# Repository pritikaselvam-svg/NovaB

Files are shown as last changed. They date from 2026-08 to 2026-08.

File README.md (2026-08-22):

# 🎧 NovaBuds

### An end-to-end headphone concept combining industrial design, ergonomics, embedded electronics and custom PCB development.

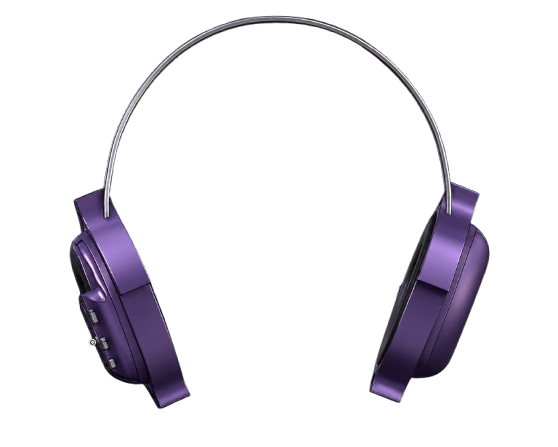
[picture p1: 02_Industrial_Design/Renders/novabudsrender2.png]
NovaB Hero


---

## What if I could take a pair of headphones from a concept sketch all the way to the electronics?

NovaBuds started with that question.

What began as a headphone design exercise turned into an exploration of what happens when **industrial design and electrical engineering are developed together**.

I designed the headphone form and ergonomics, developed the earcup and headband in CAD, designed the electronics architecture, built the schematic in KiCad, created a custom-shaped PCB around the product geometry, planned the embedded system and designed the ambient display interface.

The goal was not just to make a headphone that looked interesting.

It was to understand what it takes to make the **product, electronics and interaction work as one system.**

---

# ✦ Project Snapshot

| | |
|---|---|
| **Project** | NovaBuds |
| **Type** | Headphone / Wearable Electronics |
| **Focus** | Industrial Design × Embedded Systems |
| **CAD** | Onshape |
| **PCB Design** | KiCad |
| **MCU** | ESP32-S3-WROOM |
| **Charging** | BQ24074 |
| **Regulation** | AP2112K 3.3 V |
| **Audio** | I²S + MAX98357A |
| **Sensing** | Hall-effect sensor |
| **Interface** | TFT ambient display + physical buttons |
| **PCB** | Custom-shaped |
| **Status** | Engineering prototype in development |

---

# 01 — The Idea

Most headphone projects begin with either the industrial design or the electronics.

I wanted to explore both at the same time.

The starting point was a wearable form that could accommodate:

- a custom earcup geometry
- a headband structure
- a local display
- physical controls
- a battery
- audio electronics
- a wireless MCU
- a custom PCB

That immediately created an interesting constraint:

> **The electronics couldn't simply be designed first and placed inside a box afterwards.**

The product geometry had to influence the electronics.

And the electronics had to influence the product geometry.

---

# 02 — Product Direction

NovaBuds is designed around three ideas:

### 01. Product form

A distinctive earcup geometry developed around the human-facing side of the product rather than around a conventional rectangular electronics package.

### 02. Ambient interaction

A small display provides glanceable information such as playback state, battery and connectivity without requiring the user to constantly reach for a phone.

### 03. Integrated engineering

The mechanical enclosure, PCB and interaction system are treated as parts of the same product rather than independent projects.

---

# 03 — From Sketch to CAD

The first iterations were developed through physical sketches and form exploration.

The form was then developed in Onshape into the final earcup and headband geometry.

### CAD development

The CAD work focused on:

- earcup geometry
- headband structure
- component packaging
- display placement
- button placement
- internal volume
- PCB integration
- enclosure transitions

The final assembly was developed as a complete headphone rather than as isolated parts.

---

# 04 — Ergonomics

Because the product is worn directly on the head, the geometry had to be considered from the user's perspective.

The main ergonomic considerations were:

- ear clearance
- contact surfaces
- enclosure thickness
- edge transitions
- button reach
- display visibility
- headband geometry
- internal component clearance

The controls were positioned on the earcup so that common interactions could be performed without relying entirely on a phone.

The display was treated as an **ambient information surface** rather than a miniature smartphone screen.

> The current geometry is a design exploration. Formal anthropometric studies and physical user testing are planned for future iterations.

---

# 05 — Electronics Architecture

The electronics were designed around an ESP32-S3 as the central controller.

```text
                         ┌────────────────────┐
                         │      ESP32-S3      │
                         │   MCU + Wireless   │
                         └─────────┬──────────┘
                                   │
              ┌────────────────────┼────────────────────┐
              │                    │                    │
              ▼                    ▼                    ▼
         TFT Display           Buttons             Hall Sensor
              │
              │
              └─────────────────────┐
                                    │
                                    ▼
ESP32-S3 ─────── I²S ───────► MAX98357A ───────► Speaker

USB-C ───────► BQ24074 ───────► Li-ion Battery
                    │
                    ▼
                 AP2112K
                    │
                   3V3
                    │
                    └──────► Digital Electronics

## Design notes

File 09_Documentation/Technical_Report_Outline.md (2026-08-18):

# NovaBuds Technical Report

## 1. Introduction

Motivation for taking a headphone from concept to engineering
implementation.

## 2. Design Objectives

Ergonomics, product identity, embedded interaction, custom electronics
and compact packaging.

## 3. Industrial Design

Sketches, CAD evolution, enclosure geometry, headband, controls and
display.

## 4. Electronics

ESP32-S3, charging, regulation, audio, display, Hall sensing and
buttons.

## 5. PCB

Schematic, component selection, footprints, placement, custom outline,
routing, copper and DRC.

## 6. Firmware

Architecture and planned peripheral interfaces.

## 7. UI/UX

Ambient display and physical control concept.

## 8. Manufacturing

PCB fabrication, enclosure manufacturing and assembly.

## 9. Validation

Separate design assumptions from measured results.

## 10. Limitations

State what has not been physically tested.

## 11. Future Work

Fabrication, bring-up, firmware, acoustic testing and ergonomic testing.

## 12. Conclusion

Position NovaBuds as an integrated product-development exercise.

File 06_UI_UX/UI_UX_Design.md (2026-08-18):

# UI / UX Design

## Concept

Use an ambient display to surface useful information without requiring a
phone for every interaction.

## Information hierarchy

### Home

Connection, battery, playback state.

### Now Playing

Artwork, title, artist, playback state.

### Controls

Previous, play/pause, next, volume.

### Settings

Bluetooth, display and audio.

## Physical controls

Three buttons provide direct interaction. Exact mapping should be
validated through user testing.

## Design principles

-   Glanceable
-   Minimal
-   Clear state changes
-   Low interaction cost
-   Consistent hierarchy

## Validation questions

-   Can the current state be understood in two seconds?
-   Can common controls be used without a phone?
-   Is the display readable while worn?
-   Are icons understandable?

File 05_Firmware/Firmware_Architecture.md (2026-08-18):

# Firmware Architecture

## Target

ESP32-S3

## Proposed structure

``` text
main
├── bluetooth
├── audio
├── display
├── buttons
├── hall_sensor
├── power
└── ui_state
```

## Responsibilities

**Bluetooth:** pairing, connection state, control events.

**Display:** initialization, rendering, status updates.

**Buttons:** GPIO reading, debounce, action mapping.

**Hall sensor:** state detection and transitions.

**Audio:** I²S configuration and audio path.

**UI state:** HOME, NOW_PLAYING, VOLUME, BATTERY, BLUETOOTH, SETTINGS.

## Status

Architecture planned. Do not claim firmware functionality until it is
implemented and tested on hardware.

## Bring-up milestones

1.  Boot/serial.
2.  GPIO.
3.  Display.
4.  Buttons.
5.  Hall sensor.
6.  I²S.
7.  Amplifier/audio.
8.  Bluetooth.
9.  UI state machine.
10. Integrated power states.

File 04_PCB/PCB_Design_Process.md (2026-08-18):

# PCB Design Process

## Workflow

Schematic → Annotate → Footprints → ERC → Update PCB → Board outline →
Placement → Routing → Copper pour → DRC → 3D inspection → Gerbers

## Placement priorities

1.  Mechanical interfaces.
2.  ESP32-S3 antenna keepout.
3.  Power subsystem grouping.
4.  Audio path.
5.  Low-speed control signals.

## Routing priorities

1.  Power.
2.  Ground/return paths.
3.  Clock/data interfaces.
4.  I²S.
5.  Low-speed GPIO.

## Custom board outline

The outer boundary belongs on **Edge.Cuts** and must be a single closed,
non-self-intersecting contour.

Reference geometry should be placed on a user drawing layer, not
Edge.Cuts.

## Copper

Use a ground copper pour where appropriate and refill after routing
changes.

## DRC

Run DRC after major routing, outline, footprint and copper changes. Save
a screenshot of the final result.

## Status

-   Schematic: designed
-   Footprints: assigned
-   Placement: iterated
-   Routing: iterated
-   Copper pour: completed
-   Custom outline: created
-   DRC: iterated
-   Fabrication: pending

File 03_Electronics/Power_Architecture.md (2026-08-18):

# Power Architecture

``` text
USB-C VBUS
     │
     ▼
BQ24074
     ├────────► Li-ion Battery
     │
     ▼
AP2112K
     │
     ▼
3V3
 ├── ESP32-S3
 ├── Hall sensor
 ├── Display logic if compatible
 └── Other digital peripherals
```

## BQ24074

Document and verify: - ISET - ILIM - TS - EN1 - EN2 - CE - BAT - OUT -
GND/VSS

Exact resistor values and control states must be checked against the
selected BQ24074 datasheet and intended battery.

## 3.3 V

AP2112K input/output capacitors must be placed according to the
datasheet and close to the regulator pins.

## USB-C

For a USB-C power-only sink architecture, CC pins require appropriate
pull-down resistors. Verify the exact connector footprint and
implementation.

## Validation

Measure USB VBUS, charger output, battery voltage, regulator
input/output, 3V3 ripple, charging current and regulator temperature.

Do not connect a battery to a newly fabricated board until the power
path has been inspected and checked.

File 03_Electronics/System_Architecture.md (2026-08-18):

# Electronics System Architecture

``` text
                         ┌────────────────────┐
                         │      ESP32-S3      │
                         │   Main Controller  │
                         └─────────┬──────────┘
                                   │
          ┌────────────────────────┼─────────────────────────┐
          │                        │                         │
          ▼                        ▼                         ▼
      TFT Display             Hall Sensor               Buttons
                                   │
                                   │
                                I/O
                                   │
ESP32-S3 ───── I²S ─────► MAX98357A ─────► Speaker

USB-C ─────► BQ24074 ─────► Battery
                  │
                  ▼
             AP2112K
                  │
                 3V3
                  │
          Digital electronics
```

## Power

USB-C provides external power. BQ24074 manages the rechargeable
battery/power path. AP2112K provides the regulated digital 3.3 V rail.

## Digital

ESP32-S3 is the central controller for wireless connectivity and
peripheral control.

## Audio

ESP32-S3 → I²S → MAX98357A → speaker.

## Display

The display is mechanically separated from the main PCB and connected
through a dedicated connector. The exact pinout must match the chosen
display module.

## Hall sensor

A Hall-effect sensor is connected to a GPIO and positioned relative to a
magnet/mechanical feature.

## Engineering note

Final pin assignments, current requirements, decoupling, charge settings
and display protocol must be verified against the exact component/module
datasheets before fabrication.

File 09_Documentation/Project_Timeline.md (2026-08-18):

# Project Timeline

| Phase | Dates | Output |
| --- | --- | --- |
| **Concept** | **May 06–09, 2026** | Product direction |
| **Sketching** | **May 10–16, 2026** | Initial form |
| **Ergonomics** | **May 17–23, 2026** | Earcup geometry + control placement |
| **CAD** | **May 24–Jun 07, 2026** | Full headphone assembly |
| **Electronics Architecture** | **Jun 08–12, 2026** | System block diagram |
| **Schematic** | **Jun 13–22, 2026** | KiCad schematic |
| **Footprints** | **Jun 23–26, 2026** | Component footprints assigned |
| **PCB Placement** | **Jun 27–Jul 03, 2026** | Custom-shaped component layout |
| **Routing** | **Jul 04–14, 2026** | Routed PCB |
| **DRC + PCB Refinement** | **Jul 15–19, 2026** | Cleaned PCB + copper pour |
| **UI / UX** | **Jul 20–26, 2026** | Display screens + interaction concept |
| **Firmware Architecture** | **Jul 27–31, 2026** | Embedded software structure |
| **Fabrication** | **Aug 01–08, 2026** | Physical PCB |
| **Hardware Bring-up** | **Aug 09–15, 2026** | Initial electronics testing |
| **Integration** | **Aug 16–23, 2026** | Complete prototype |
| **Validation** | **Aug 24–30, 2026** | Electrical, ergonomic + functional measurements |
| **Final Documentation** | **Aug 31–Sep 06, 2026** | Portfolio + technical documentation |

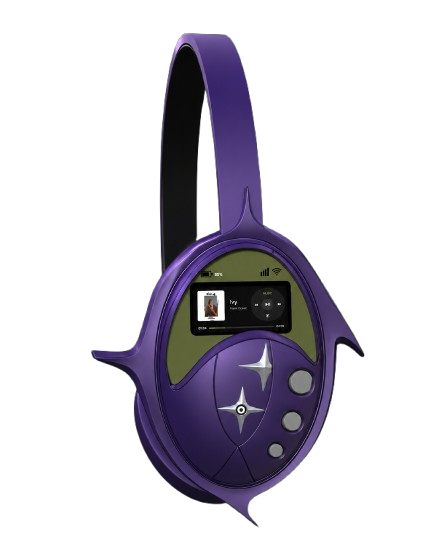
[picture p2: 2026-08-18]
10_Media/novabudsrender1.png

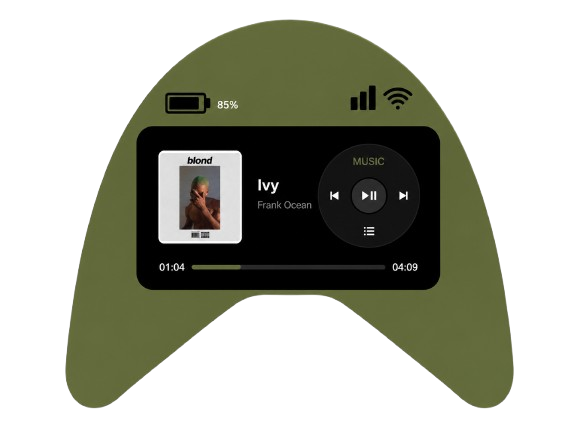
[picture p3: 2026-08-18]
06_UI_UX/NovaB UI.png

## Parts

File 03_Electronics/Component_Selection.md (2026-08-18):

# Component Selection

  Component        Function                     Why
  ---------------- ---------------------------- ---------------------------------
  ESP32-S3-WROOM   MCU/wireless                 Wireless + flexible peripherals
  BQ24074          Li-ion charging/power path   Dedicated battery management
  AP2112K          3.3 V LDO                    Compact digital regulation
  MAX98357A        I²S amplifier                Digital audio path
  A1104xLH         Hall sensor                  Solid-state magnetic sensing
  TFT display      Ambient interface            Local contextual information
  USB-C            Power input                  Common modern connector
  Li-ion battery   Energy storage               Rechargeable portable power
  Speaker          Audio output                 Acoustic transducer
  Push buttons     User input                   Tactile controls

## Verification before fabrication

-   [ ] Verify exact ESP32 module pinout.
-   [ ] Verify BQ24074 ISET/ILIM/TS/EN1/EN2/CE configuration.
-   [ ] Verify AP2112K exact output variant and capacitor requirements.
-   [ ] Verify MAX98357A package, supply and speaker requirements.
-   [ ] Verify exact display voltage, protocol and pinout.
-   [ ] Verify Hall sensor variant and output.
-   [ ] Verify USB-C footprint and CC resistor implementation.
-   [ ] Verify battery protection requirements.

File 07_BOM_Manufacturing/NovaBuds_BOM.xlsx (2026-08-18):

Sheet: BOM
Reference | Component | Function | Package / Footprint | Qty | Notes | Status
U1 | ESP32-S3-WROOM | MCU / wireless | RF module | 1 | Verify exact module pinout + antenna keepout | Designed
U2 | MAX98357A | I²S audio amplifier | Verify exact package | 1 | Verify supply and speaker requirements | Designed
U3 | A1104xLH | Hall sensor | SOT-23 | 1 | Verify exact variant | Designed
U4 | BQ24074 | Li-ion charger / power path | QFN | 1 | Verify ISET/ILIM/TS/EN1/EN2/CE | Designed
U6 | AP2112K-1.2 | 3.3 V LDO | SOT-23-5 | 1 | Verify exact ordering code | Designed
BT1 | 1-cell Li-ion battery | Energy storage | Battery connector/cell | 1 | Select protected cell/system | Concept
P1 | USB-C receptacle | Charging input | USB-C SMD | 1 | Verify exact footprint + CC network | Designed
LS1 | Speaker | Audio output | Mechanical part | 1 | Match amplifier requirements | Concept
J1 | 12-pin connector | Main interconnect | Verify selected footprint | 1 | Verify pinout | Designed
J2 | 12-pin connector | Interconnect | Verify selected footprint | 1 | Verify pinout | Designed
J3 | 8-pin connector | Display interface | 8-pin | 1 | Must match selected display | Designed
SW1 | Push button | User input | Verify selected footprint | 1 | GPIO | Designed
SW2 | Push button | User input | Verify selected footprint | 1 | GPIO | Designed
SW3 | Push button | User input | Verify selected footprint | 1 | GPIO | Designed

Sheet: Passives
Reference | Value | Function | Qty | Notes
R1 | 10k | ESP32 EN pull-up | 1 | Close to EN
R2 | 5.1k | USB-C CC pull-down | 1 | Verify CC implementation
R3 | 1.5k | BQ24074 configuration | 1 | Verify against datasheet
R4 | 2k | BQ24074 configuration | 1 | Verify against datasheet
R5 | 1.5k | BQ24074 configuration | 1 | Verify against datasheet
R6 | 1.5k | BQ24074 configuration | 1 | Verify against datasheet
R7 | 10k | GPIO pull-up where applicable | 1 | Verify firmware/hardware architecture
C1 | 10uF | Power decoupling | 1 | Near power IC
C2 | 10uF | Power decoupling | 1 | Near regulator
C3 | 10uF | Bulk decoupling | 1 | Near digital supply
C4 | 0.1uF | High-frequency decoupling | 1 | Near IC supply
C5 | 10uF | Bulk decoupling | 1 | Near digital supply

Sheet: PreFab_Checklist
Item | Check | Status
ESP32-S3 | Exact module/footprint verified | Pending
BQ24074 | Charge settings and control pins verified | Pending
AP2112K | Exact variant and capacitor requirements verified | Pending
MAX98357A | Exact package/speaker requirements verified | Pending
Display | Exact voltage/protocol/pinout verified | Pending
USB-C | Footprint and CC network verified | Pending
Battery | Protected cell/system selected | Pending
PCB | DRC clean | Pending
Edge.Cuts | Single closed outline | Pending
Connectors | Physical pin numbering verified | Pending

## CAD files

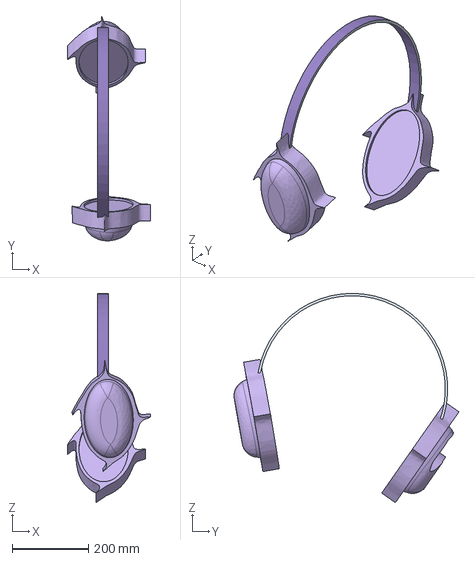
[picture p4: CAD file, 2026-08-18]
02_Industrial_Design/CAD/Assembly 1.step
217.7 x 588.7 x 547.5 mm

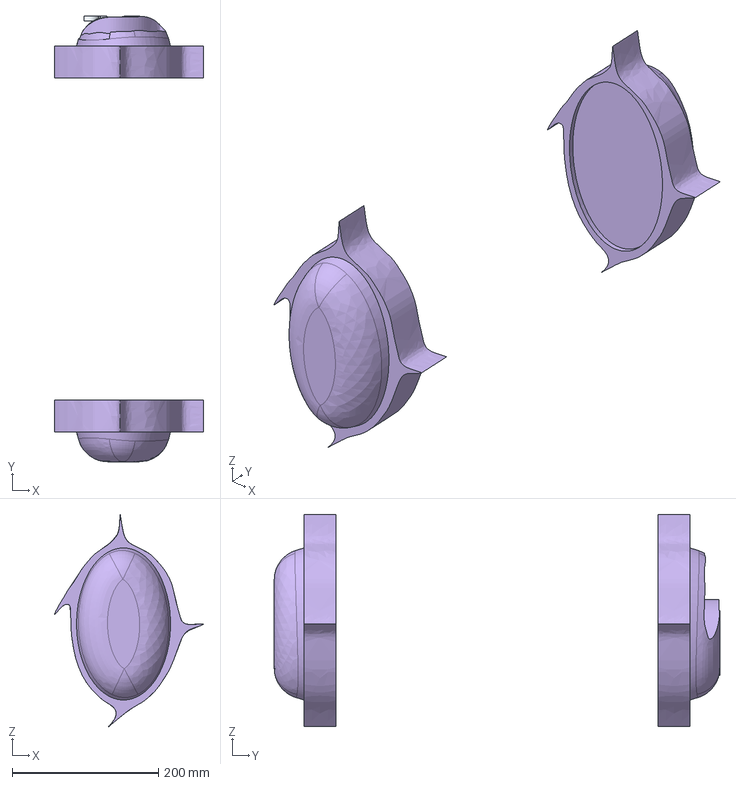
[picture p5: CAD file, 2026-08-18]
02_Industrial_Design/CAD/Part Studio 1.step
204.3 x 609.6 x 290.1 mm

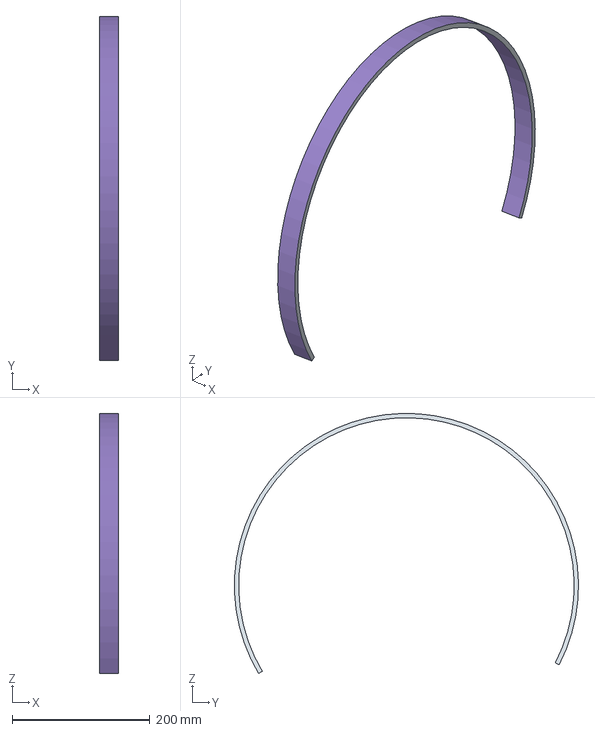
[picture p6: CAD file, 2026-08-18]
02_Industrial_Design/CAD/Part Studio 2.step
27.9 x 499.5 x 377.7 mm

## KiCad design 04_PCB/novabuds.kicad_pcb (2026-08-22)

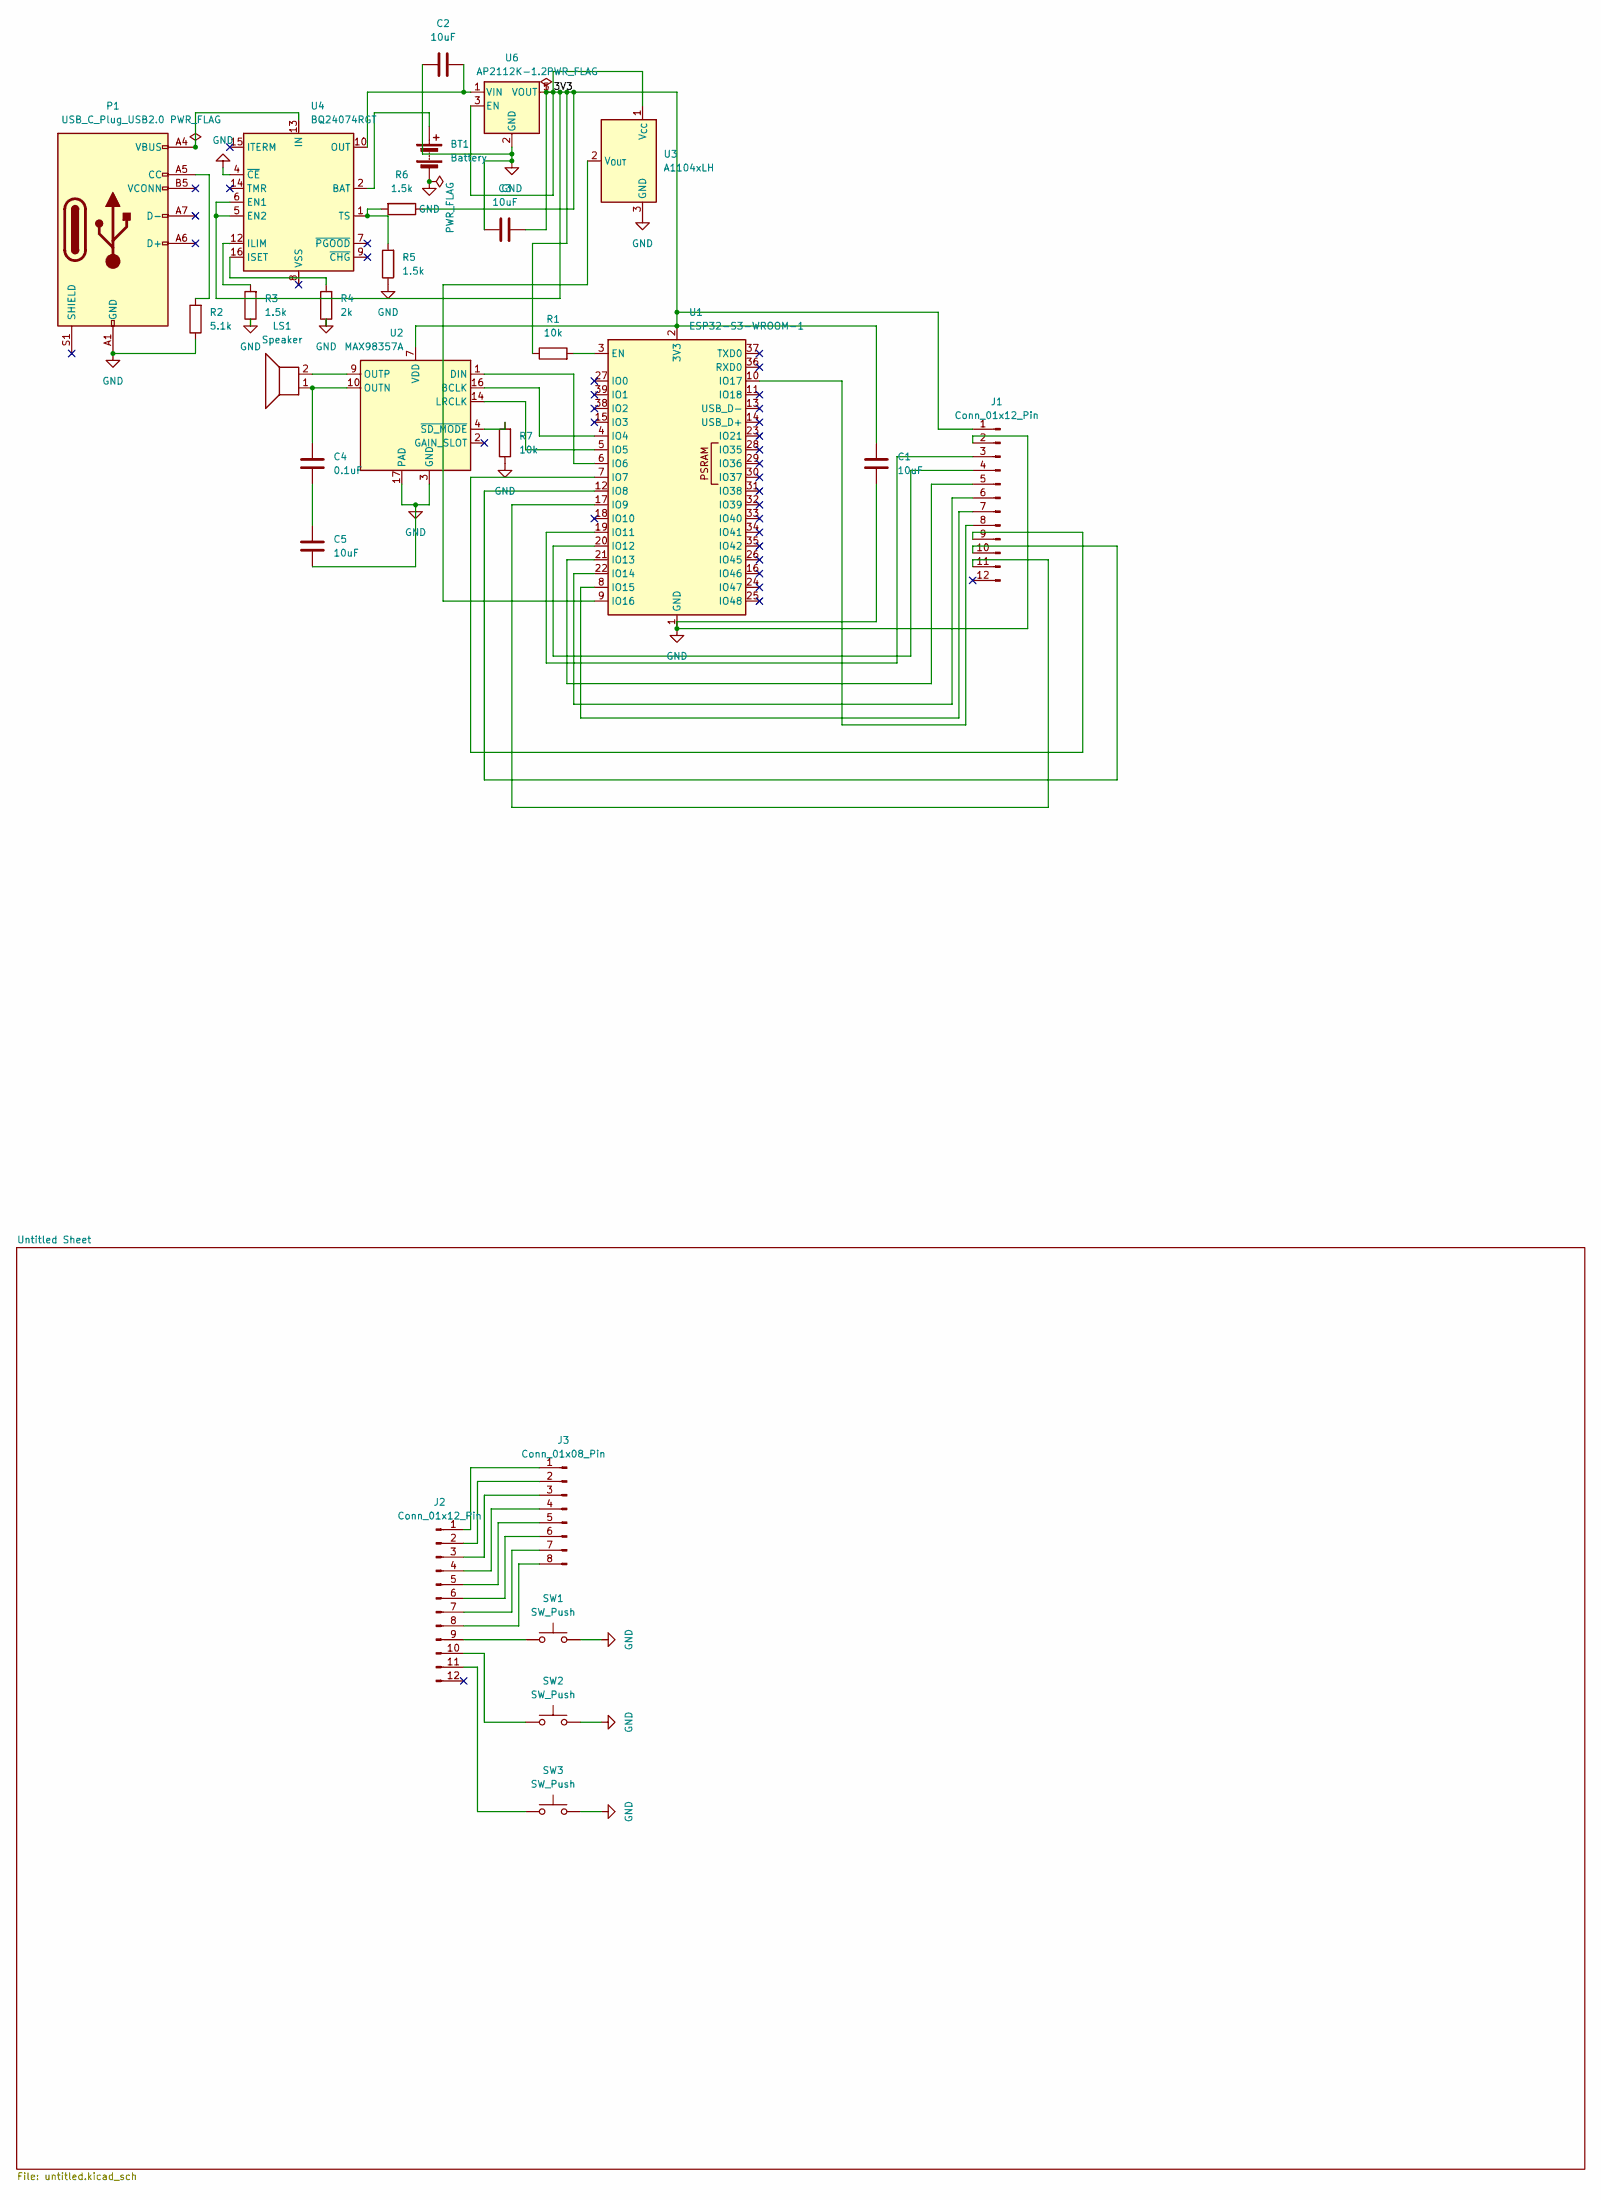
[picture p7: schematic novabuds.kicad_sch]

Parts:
BT1: Battery; JST_PH_B2B-PH-K_1x02_P2.00mm_Vertical
C1, C2, C3, C5: 10uF; C_0805_2012Metric
C4: 0.1uF; C_0805_2012Metric
J1, J2: Conn_01x12_Pin; PinHeader_1x12_P2.54mm_Vertical
J3: Conn_01x08_Pin; PinHeader_1x08_P2.54mm_Vertical
LS1: Speaker; PinHeader_1x02_P2.54mm_Vertical
P1: USB_C_Plug_USB2.0; USB_C_Receptacle_HRO_TYPE-C-31-M-12
R1, R7: 10k; R_0805_2012Metric
R2: 5.1k; R_0805_2012Metric
R3, R5, R6: 1.5k; R_0805_2012Metric
R4: 2k; R_0805_2012Metric
SW1, SW2, SW3: SW_Push; SW_PUSH_6mm
U1: ESP32-S3-WROOM-1
U2: MAX98357A; TQFN-16-1EP_3x3mm_P0.5mm_EP1.23x1.23mm
U3: A1104xLH; SOT-23W
U4: BQ24074RGT; VQFN-16-1EP_3x3mm_P0.5mm_EP1.6x1.6mm
U6: AP2112K-1.2; SOT-23-5

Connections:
/3V3: C1.1, C3.2, J1.1, R1.1, R6.1, U1.2 (3V3), U2.7 (VDD), U2.8 (VDD), U3.1 (V_{CC}), U4.5 (EN2), U4.6 (EN1), U6.3 (EN), U6.5 (VOUT)
GND: BT1.2 (-), C1.2, C2.1, C3.1, C5.2, J1.2, P1.A1 (GND), P1.A12 (GND), P1.B1 (GND), P1.B12 (GND), R2.1, R3.1, R4.1, R5.1, R7.1, SW1.2, SW2.2, SW3.2, U1.1 (GND), U1.40 (GND), U1.41 (GND), U2.3 (GND), U2.11 (GND), U2.15 (GND), U2.17 (PAD), U3.3 (GND), U4.4 (~CE), U6.2 (GND)
unnamed: BT1.1 (+), U4.2 (BAT), U4.3 (BAT)
unnamed: C4.2, C5.1
unnamed: J1.3, U1.19 (IO11)
unnamed: J1.4, U1.20 (IO12)
unnamed: J1.5, U1.21 (IO13)
unnamed: J1.6, U1.22 (IO14)
unnamed: J1.7, U1.8 (IO15)
unnamed: J1.8, U1.10 (IO17)
unnamed: J1.9, U1.7 (IO7)
unnamed: J1.10, U1.12 (IO8)
unnamed: J1.11, U1.17 (IO9)
unnamed: J2.1, J3.1
unnamed: J2.2, J3.2
unnamed: J2.3, J3.3
unnamed: J2.4, J3.4
unnamed: J2.5, J3.5
unnamed: J2.6, J3.6
unnamed: J2.7, J3.7
unnamed: J2.8, J3.8
unnamed: J2.9, SW1.1
unnamed: J2.10, SW2.1
unnamed: J2.11, SW3.1
unnamed: P1.A5 (CC), R2.2
unnamed: R1.2, U1.3 (EN)
unnamed: U1.4 (IO4), U2.16 (BCLK)
unnamed: U1.5 (IO5), U2.14 (LRCLK)
unnamed: U1.6 (IO6), U2.1 (DIN)
unnamed: U1.9 (IO16), U3.2 (V_{OUT})
unnamed: C4.1, LS1.1, U2.10 (OUTN)
unnamed: LS1.2, U2.9 (OUTP)
unnamed: R7.2, U2.4 (~SD_MODE)
unnamed: R3.2, U4.12 (ILIM)
unnamed: P1.A4 (VBUS), P1.A9 (VBUS), P1.B4 (VBUS), P1.B9 (VBUS), U4.13 (IN)
unnamed: R4.2, U4.16 (ISET)
unnamed: R5.2, R6.2, U4.1 (TS)
unnamed: C2.2, U4.10 (OUT), U4.11 (OUT), U6.1 (VIN)

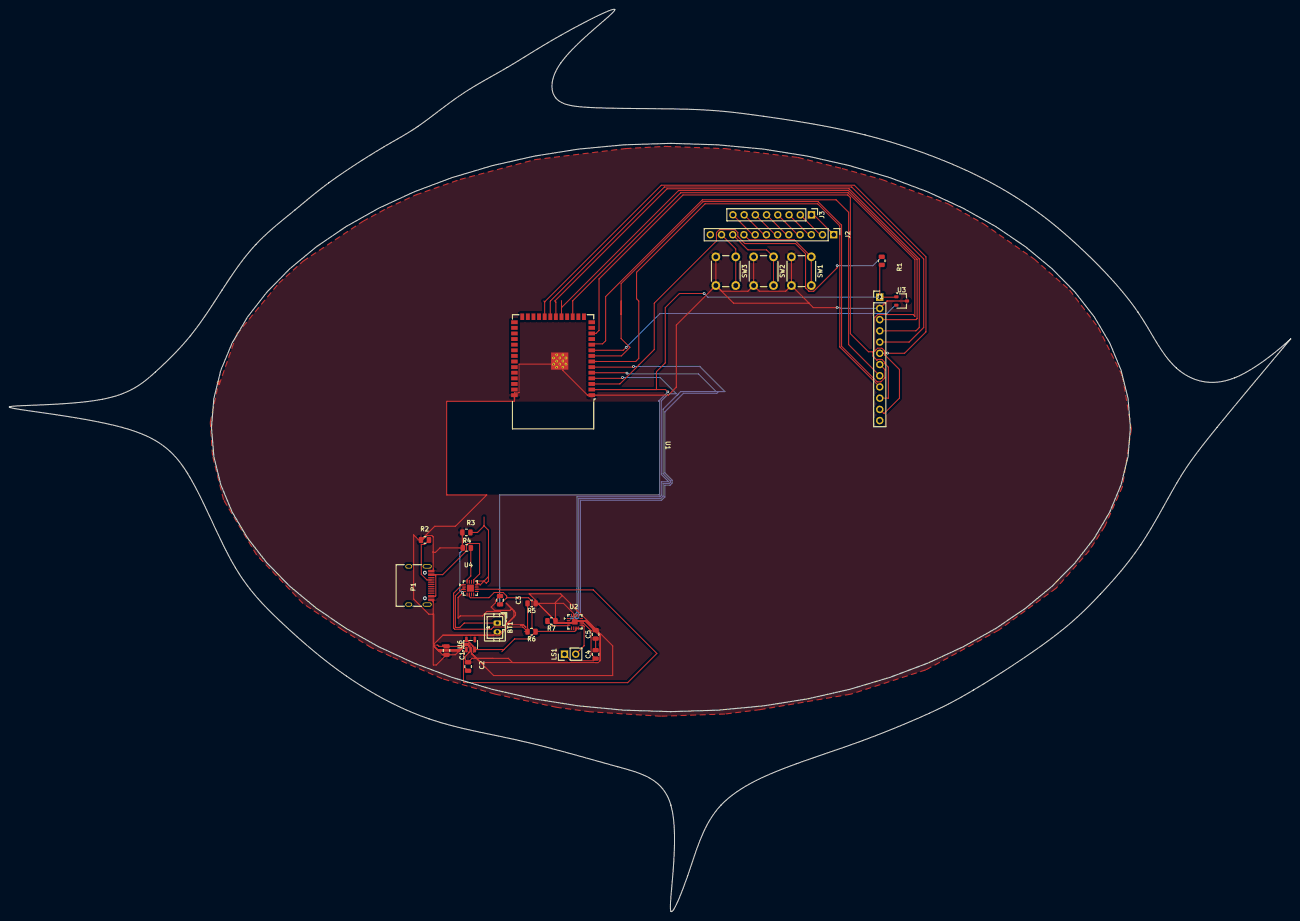
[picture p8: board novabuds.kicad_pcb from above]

Board: 2 copper layers, 290.1 x 204.3 mm, 26 parts (0 on the bottom side), 38 nets.

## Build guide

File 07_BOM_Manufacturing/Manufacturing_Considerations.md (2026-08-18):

# Manufacturing & Design for Assembly

## PCB

Consider: - 2-layer manufacturing capability - trace/space - via size -
board edge tolerances - connector accessibility - component
availability - assembly side

## Enclosure

Consider: - wall thickness - draft angles - screw bosses - snap fits -
speaker mounting - display retention - button retention - PCB mounting -
battery retention - serviceability

## Potential assembly sequence

1.  Install speaker.
2.  Install PCB.
3.  Connect battery.
4.  Install display/interface.
5.  Install buttons.
6.  Verify wiring.
7.  Close enclosure.
8.  Install cosmetic shell.

## Battery safety

Use an appropriately protected cell/system. Secure the battery, protect
it from sharp edges and excessive heat, and verify the final charging
architecture before use.

## DFM questions

-   Can every component be sourced?
-   Can the PCB be assembled?
-   Can the enclosure be manufactured?
-   Can the battery be replaced?
-   Are connectors accessible?
-   Can the PCB be removed without damaging the enclosure?

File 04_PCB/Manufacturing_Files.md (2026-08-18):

# PCB Manufacturing Deliverables

When the design is frozen, export: - Gerbers - Drill files - BOM -
Pick-and-place if outsourced - Fabrication drawing if required

## Pre-fabrication checklist

-   [ ] Schematic and PCB synchronized.
-   [ ] No unintended DRC violations.
-   [ ] Board outline closed.
-   [ ] Mounting holes verified.
-   [ ] Connector footprints physically verified.
-   [ ] ESP32 antenna keepout respected.
-   [ ] Silkscreen checked.
-   [ ] Polarity/orientation checked.
-   [ ] Battery connector polarity checked.
-   [ ] USB-C footprint verified.
-   [ ] Display connector pin numbering verified.
-   [ ] Manufacturer capabilities match trace/clearance choices.

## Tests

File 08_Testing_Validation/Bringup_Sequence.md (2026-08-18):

# Hardware Bring-up Sequence

## Stage 1: visual inspection

-   [ ] Component orientation
-   [ ] Connector orientation
-   [ ] Battery polarity
-   [ ] USB-C footprint
-   [ ] ESP32 orientation

## Stage 2: unpowered continuity

-   [ ] GND continuity
-   [ ] 3V3-to-GND short check
-   [ ] Battery path
-   [ ] USB VBUS path
-   [ ] Critical connector pins

## Stage 3: power

Test only the charging/regulation section first.

Measure USB input, charger output, regulator input and regulator output.

## Stage 4: MCU

Only after 3V3 is confirmed: - power ESP32-S3 - flash test firmware -
verify serial output

## Stage 5: peripherals

Bring up one at a time: 1. Buttons 2. Hall sensor 3. Display 4. Audio
amplifier 5. Bluetooth/audio

## Stage 6: integration

Combine subsystems only after individual blocks work.

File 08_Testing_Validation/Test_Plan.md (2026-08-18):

# Test & Validation Plan

## Mechanical

-   Earcup fit
-   PCB clearance
-   Button travel
-   Display visibility
-   Headband fit

## Power

-   USB input voltage
-   Charger output
-   Battery voltage/current
-   3V3 voltage
-   3V3 ripple
-   Regulator temperature
-   Idle current
-   Peak current

## Digital

-   ESP32 boot
-   GPIO
-   buttons
-   Hall sensor
-   display initialization
-   display refresh

## Audio

-   I²S configuration
-   amplifier initialization
-   speaker output
-   volume
-   noise
-   thermal behaviour

## PCB

-   visual inspection
-   solder bridge inspection
-   continuity
-   power-to-ground short check
-   rail voltage
-   connector pin verification
-   DRC

## Status language

**DESIGNED** = CAD/schematic/PCB exists.

**SIMULATED** = checked in software/design tools.

**PROTOTYPED** = physically manufactured.

**TESTED** = physically measured.

**VALIDATED** = tested successfully against a defined requirement.
